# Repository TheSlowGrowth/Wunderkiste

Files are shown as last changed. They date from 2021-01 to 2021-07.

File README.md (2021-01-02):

# Wunderkiste




A portable music player for children

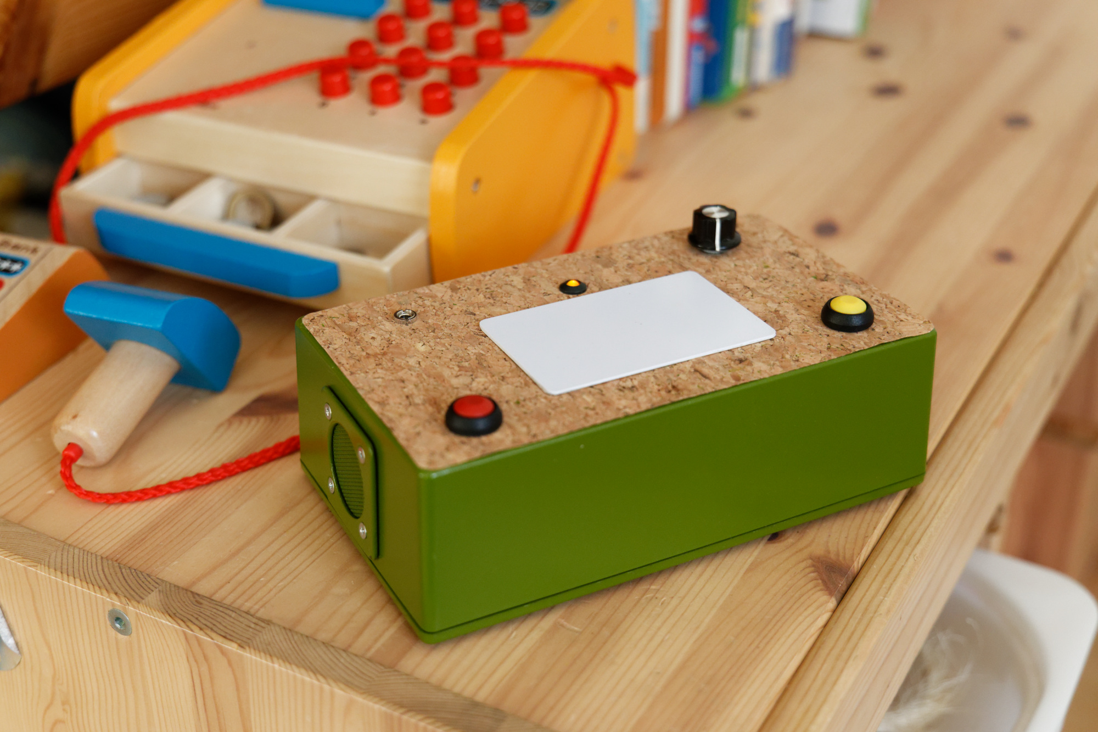
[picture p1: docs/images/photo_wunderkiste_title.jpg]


Wunderkiste is a portable music player for young children. It's designed to be very easy to use so that even a 2 year-old child can quickly understand how it works. The whole projects is entirely open source so that YOU can build and modify it easily.

- Music is selected by placing a card / tag / figurine / cuddly toy on the top surface of Wunderkiste.
- Speakers are integreated, but headphones can be used, too.
- The integrated battery lasts multiple days of heavy use and can simply be charged with a USB phone charger.
- Music is stored as `*.mp3` files on an SD card. Wunderkiste can hold a very large library of music.
- New music can easily be added without any special tools or software.
- The build uses mostly through-hole components and should be doable by anyone with basic knowledge of soldering and a handfull of tools.
- The firmware can be updated easily.

# Building and using Wunderkiste

We collected a lot of information in the [Wiki tab of this repository](https://github.com/TheSlowGrowth/Wunderkiste/wiki). Here are some links to get started:

- [Download the latest release](https://github.com/TheSlowGrowth/Wunderkiste/releases/latest)
- [View the user manual](https://github.com/TheSlowGrowth/Wunderkiste/wiki/3.-How-to-use) (Work in progress)
- [View the build guide](https://github.com/TheSlowGrowth/Wunderkiste/wiki/2.-How-to-build) (Work in progress)
- [Report issues and bugs](https://github.com/TheSlowGrowth/Wunderkiste/issues)
- [Any contribution to the project is highly appreciated!](https://github.com/TheSlowGrowth/Wunderkiste/wiki/5.-How-to-contribute-to-the-project)

# Project structure

This software repository is the place where we collect everything needed to build, use, improve and customize your Wunderkiste.

The repository contains
- The source code for the firmware in the `firmware` directory.
- The hardware design files for the printed circuit boards in the `hardware` directory.
- Documentation and guides in the `docs` directory.
- The sources for the [Wiki](https://github.com/TheSlowGrowth/Wunderkiste/wiki) in the `docs/wiki` directory. They are automatically copied to the project wiki when pull requests are merged.
- CI actions in the `.github` directory (automated tests, release artifacts generation, etc.)

In addition to that, the github page contains
- [The Wiki tab](https://github.com/TheSlowGrowth/Wunderkiste/wiki) where you'll find a lot of resources
- [The Releases tab](https://github.com/TheSlowGrowth/Wunderkiste/releases) where you'll find all releases and the corresponding firmware images and other documents.

# How to contribute

Wunderkiste is open to use and modify by everyone. When we work together on this project, we can truely make something unique and wonderful. Please don't be shy to help improve this project!

- If you find something that you feel needs an improvement, feel free to [open an issue on the issues tab](https://github.com/TheSlowGrowth/Wunderkiste/issues) and let us know.
- [Browse the issues tab](https://github.com/TheSlowGrowth/Wunderkiste/issues) to see what's to do and where help is needed.
- [Fork this repo and make some changes](https://guides.github.com/activities/forking/), then open a pull request. We'll review your changes and merge them into this repository.

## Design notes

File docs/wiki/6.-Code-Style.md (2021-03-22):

# Code Style

## General

- Use clang-format. The clang-format spec is enforced in pull requests.
- C++ files end on `.cpp`
- C files end on `.c`
- Header files for both languages end on `.h`
- C++ code is preferred over C code
- Each C++ header file has `#pragma once` 
- Each C header has an include guard: 
```cpp
#ifndef __DAC_H__
#define __DAC_H__

#endif // #ifndef __DAC_H__
```
- Use `""` for including local files, use `<>` for system headers
- Never use `using namespace` in a header file
- Where possible, unit tests are provided
- Avoid preprocessor macros where possible, use `static constexpr` variables instead
- Prefer `using TypeA = typeB` over `typedef TypeB TypeA;`
- Be generous with comments, use doxygen comments where it makes sense.
- No dynamic memory allocation. Allocate everything statically.

## Naming

- Use descriptive names
```cpp
int numBytesReceived; // good
int nRx; // bad
```
- Use camelCase 
```cpp
int numBytesReceived; // good
int num_bytes_received; // bad
```
- Types start with an upper case letter 
```cpp
class WavFileReader;
```
- Variables and function arguments start with an lower case letter 
```cpp
int numFilesWritten;
```
- Functions start with an lower case letter 
```cpp
void setupAudioOutput();
```
- Member variables end on an underscore to destinguish them from function arguments:
```cpp
class Counter 
{
private:
    int value_;
};
```
- Preprocessor macros are all upper case with snake_case_formatting:
```cpp
#define PLEASE_DONT_USE_MACROS_WHEN_POSSIBLE
```

## Strong types, safety, readability

- Prefer strong types
- Use `enum class` instead of `enum`
- Don't use raw pointers unless that's strictly required
- Prefer descriptive `enum class` arguments instead of `bool` arguments:
```cpp
setLeds(true, false, false); // bad
setLeds(Red::on, Blue::off, Green::off); // good
```
- Use `const` where possible:
```cpp
void doSomething(const int input); // good, communicates intention: This won't be changed during the function
void doSomething(int input); // bad, even though technically identical.
```
- Do not pass and return simple types by const ref
```cpp
int doSomething(); // good, copy the simple type
int& doSomething(); // bad, pass simple type by ref with no performance benefit, but security risks.
```
- Use `StaticVector<>` instead of C-style arrays
- Properly utilize `override` and `final`

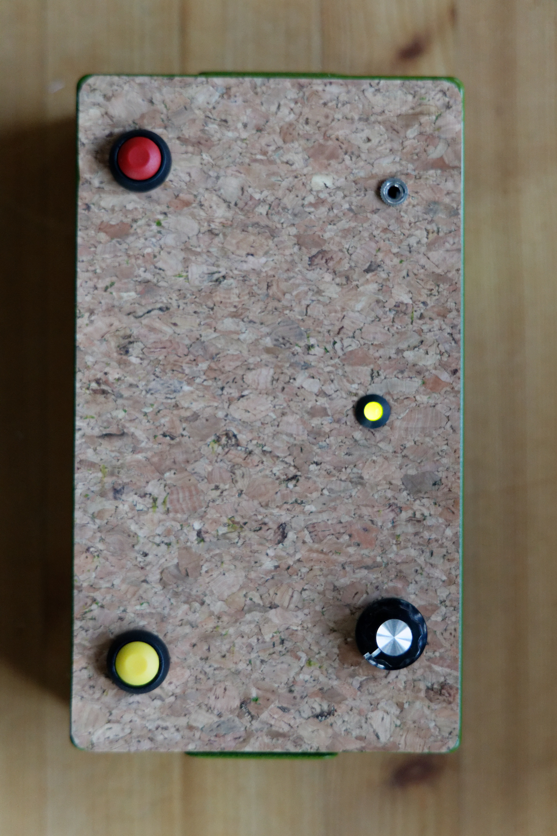
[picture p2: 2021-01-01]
docs/images/photo_top.jpg

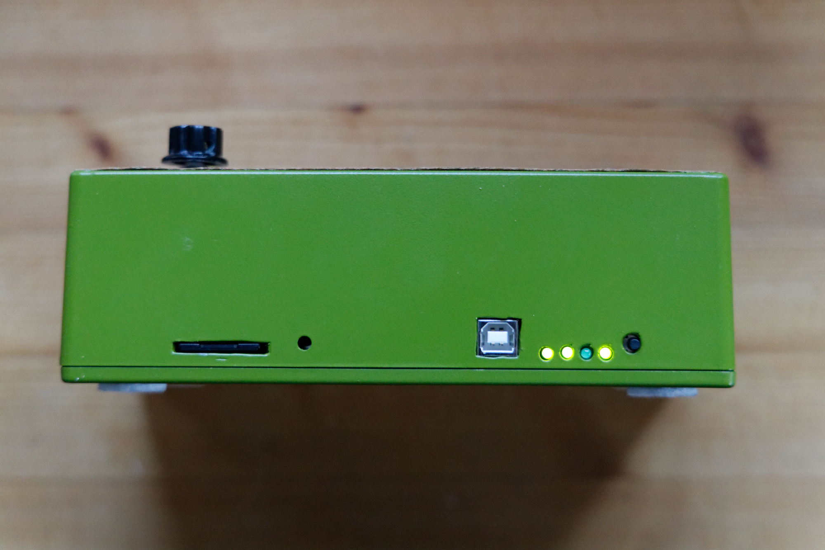
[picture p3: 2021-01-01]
docs/images/photo_back.jpg

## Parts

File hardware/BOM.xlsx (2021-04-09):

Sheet: Tabelle1
PCB designators | Description | Value | Count | reichelt.de part number | reichelt.de price per unit | reichelt.de total price | mouser.com part number | Notes
C1 C5 | Ceramic or Wima, >5V, 2.54mm pin pitch | 1u | 2 | Z5U-5 1,0µ | 0.27 € | 0.54 €
C7 C10 |  | 220n | 2 | Z5U-2,5 220N | 0.10 € | 0.21 €
C2 C3 |  | 100n | 2 | Z5U-2,5 100N | 0.06 € | 0.12 €
C4 |  | 47u | 1 | RAD FC 47/25 | 0.12 € | 0.12 €
C6 C8 C9 | Bipolar Electrolytic Capacitor | 10u Bipolar | 3 | SU-A 10U 50 | 0.21 € | 0.63 €
D1 D2 D3 D4 |  | LED | 4 | LED 3MM 2MA GN | 0.12 € | 0.48 €
D10 | Frontpanel LED R/G | 5mm, 3pin Common Anode, Red/Green | 1 | EVL 339-1SURSYGW | 0.20 € | 0.20 €
D5 D6 D7 D8 D9 |  | 1N5819 | 5 | 1N 5819 | 0.06 € | 0.30 €
J1 | Powerbank LED/Button cable | IDC Shrouded pinheader 2x5 | 1 | WSL 10G | 0.10 € | 0.10 €
 |  | IDC Socker 2x5 | 1 | PFL 10 | 0.10 € | 0.10 €
J10 | Headphones socket cable connector | Molex KK 6pin Pinheader | 1 | PSS 254/6G | 0.09 € | 0.09 € |  | Molex KK or similar, 2.54mm pin spacing
 |  | Molex KK 6pin Housing | 1 | PSK 254/6W | 0.07 € | 0.07 € |  | Molex KK or similar, 2.54mm pin spacing
J2 | SD Card Slot | SD-RSMT-2-MQ | 1 | 3M SDRSMT2MQ | 2.10 € | 2.10 €
J4 |  | 2x25 sockets | 2 | BL 2X25G8 2,54 | 0.62 € | 1.24 € | 200-SSW12501TD
J5 | USB charging connector | USB B socket Through Hole | 1 | RND 205-00858 | 0.25 € | 0.25 € |  | 2.54mm pin spacing; for the STM32F4 Discovery board
J6 J7 | PCB interconnect cable | IDC Shrouded pinheader 2x8 | 2 | WSL 16G | 0.14 € | 0.28 € |  | 2.54mm pin spacing
 |  | IDC Socket 2x8 | 2 | PFL 16 | 0.18 € | 0.36 € |  | 2.54mm pin spacing
J3 J9 | AudioIn & PowerBank Connectors | Molex KK 3pin Pinheader | 2 | PSS 254/3G | 0.05 € | 0.10 € |  | Molex KK or similar, 2.54mm pin spacing
 |  | Molex KK 3pin Housing | 2 | PSK 254/3W | 0.02 € | 0.04 € |  | Molex KK or similar, 2.54mm pin spacing
Q1 | P Channel Mosfet | BSP170P | 1 | BSP170P | 0.45 € | 0.45 €
R10 |  | 470R | 1 | METALL 470 | 0.08 € | 0.08 €
R11 |  | 2k2 | 1 | METALL 2,20K | 0.08 € | 0.08 €
R8 R9 R12 R14 R15 R17 |  | 10k | 6 | METALL 10,0K | 0.08 € | 0.49 € |  | get 10 for the same price due to the quantity discount
R13 R16 |  | 0R | 2 |  |  | 0.00 € |  | use wire bridges for full volume, attenuate volume with up to 50k resistors
R1 R2 R3 R4 R5 R6 R7 |  | 47k | 7 | METALL 47,0K | 0.08 € | 0.57 €
RV1 | Dual Gang 9mm Potentiometer | 50kA or 47kA, log, RK09 footprint, Alps/Alpha/… | 1 |  |  | 0.00 €
SW1 SW 2 | BatteryIndicator & Reset buttons | horizontal push button | 2 | TASTER 3305 | 0.21 € | 0.42 €
SW3 SW4 J8 J11 | Prev Bttn, Next Bttn, Speaker Connectors | Molex KK 2pin Pinheader | 4 | PSS 254/2G | 0.03 € | 0.12 €
 |  | Molex KK 2pin Housing | 4 | PSK 254/2W | 0.02 € | 0.08 €
U1 | Speaker Amplifier | TDA7266 | 1 | TDA 7266 | 1.70 € | 1.70 €
U2 | RFID Reader board | RFID_RC522_Board | 1 | DEBO RFID RC522 | 10.37 € | 10.37 € |  | better get this off ebay for MUCH cheaper
 |  | Crimp Pins Molex, pack of 20 | 2 | PSK-KONTAKTE | 0.29 € | 0.58 €
 | Volume Knob Cap | Mounts on RV1 | 1 | KNOPF 17-6 AL | 2.17 € | 2.17 €
 | STM32F407 Discovery board | STM32F407DISCOVERY | 1 | STM32 F407GDISC1 | 29.75 € | 29.75 € |  | Attention: Buy brand new so that you get one with version number MB997D for MUCH simpler drag&drop programming.
 | Frontpanel Pushbuttons |  | 2 | IS R3S RT | 5.80 € | 11.60 € |  | doesn't have to be that expensive, any momentary pushbutton will work just fine
 | LED frontpanel socket | 5mm | 1 | EBF A-5 S | 0.99 € | 0.99 €
 | Enclosure (screws included) | Hammond 1591XXEBK | 1 | 1591XXEBK | 9.35 € | 9.35 €
 | Headphone Jack | Stereo, switched, 3.5mm | 1 | LUM 1503-09 | 1.15 € | 1.15 € | 490-SJ1-3535 | the thread is a little short on this part but it's just enough
 | Speakers | Visaton BF 37 | 2 | VIS 2260 | 11.40 € | 22.80 €
 | Powerbank | Intenso A5200 | 1 | INTENSO 7322425 | 10.36 € | 10.36 €
 | SD Card |  | 1 | INTENSO SDHC16G | 3.49 € | 3.49 €
 | Screws for mounting the speakers & RFID | M2.5 countersunk, 10mm length max | 1 | SSK M2,5X10-200 | 2.70 € | 2.70 € |  | pack of 200
 | Nuts for mounting the speakers & RFID | M2.5 | 1 | SK M2,5-100 | 1.85 € | 1.85 € |  | pack of 100
 | Self tapping screws | # 4 x 1/4 |  |  |  | 0.00 € |  | for mounting PCB inside the Hammond enclosure; M2.5 screws might work as well
 | RFID cards, tags, stickers | Mifare Classik 1K compatible |  |  |  | 0.00 €
 | Speaker grille (?) | any metal mesh material | 1 | VIS SG 8210 | 8.95 € | 8.95 € |  | Any metal mesh will do. Cheap alternative: Frying Pan Grease Splash Guard
 | Cable, blue, 10m |  | 1 | LITZE BL | 0.78 € | 0.78 €
 | Cable, black, 10m |  | 1 | LITZE SW | 0.78 € | 0.78 €
 | Cable, red, 10m |  | 1 | LITZE RT | 0.76 € | 0.76 €
 | IDC flat cable |  | 1 | AWG 28-20F 3M | 5.25 € | 5.25 € |  | way too long. Maybe you have some leftover IDC cable from another project?
 | Rubber feet with adhesive |  | 1 | RND 455-00518 | 0.82 € | 0.82 € |  | pack of 55… some felt furniture feet will also work.
 | PCB material for the speaker covers |  | 1 | EP2CU 160X100 | 2.05 € | 2.05 €
 |  |  |  |  | Total price: | 110.45 €

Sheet: Tabelle2
Reference | Quantity | Value
C1 C5 | 2 | 1u
C7 C10 | 2 | 220n
C2 C3 | 2 | 100n
C4 | 1 | 47u
C6 | 1 | 10u
C8 C9 | 2 | 10u
D1 D2 D3 D4 | 4 | LED
D10 | 1 | LED_Dual_ACA
D5 D6 D7 D8 D9 | 5 | 1N5819
J1 | 1 | Conn_01x10
J10 | 1 | Headphones
J11 | 1 | Spkr_R
J2 | 1 | SD_Card_Det
J3 | 1 | Powerbank
J4 | 1 | STM32F4_Discovery
J5 | 1 | USB_B
J6 J7 | 2 | Conn_01x16
J8 | 1 | Spkr_L
J9 | 1 | AudioIn
Q1 | 1 | ISP75DP06LM
R10 | 1 | 470R
R11 | 1 | 2k2
R12 R14 R15 R17 | 4 | 10k
R13 R16 | 2 | 0R
R1 R2 R3 R4 R5 R6 R7 | 7 | 47k
R8 R9 | 2 | 10k
RV1 | 1 | 50kA
SW1 | 1 | BatteryIndicator
SW2 | 1 | Reset
SW3 | 1 | PrevTrack
SW4 | 1 | NextTrack
U1 | 1 | TDA7266
U2 | 1 | RFID_RC522_Board

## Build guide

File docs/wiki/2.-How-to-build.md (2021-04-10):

This guide collects all information you need to build Wunderkiste.

The build will take anywhere from a full day to multiple days depending on your tools and experience. This guide is written so that you can follow along step by step. Don't be afraid - some basic soldering experience should be the only thing you need to know to successfully finish this project.

Take your time, make breaks and keep your workspace clean. As often with tech-DIY projects it's well worth to build slowly and stay focussed. Being carefull now saves you a lot of hassle later in the troubleshooting process. Should something go wrong, there's always a way to recover. In this guide, there are troubleshooting tips with some common problems and solutions for them.

# What you should know before you start

Before you start, [download the latest release](https://github.com/TheSlowGrowth/Wunderkiste/releases/latest). It contains the firmware files, the bill of materials (BOM), drilling templates and more.

This project requires a lot of soldering. Most of it is pretty simple to do, but there are a couple of difficult parts, too. If you've done soldering projects in the past you don't have to worry. If you've never soldered anything before, I suggest you pick up a basic soldering project to get familiar with the process. It's certainly not rocket science and anyone can do it after a little bit of practice. Trying a cheap and small project first is ideal: You can quickly get familiar and feel the joy of success - but at the same time there's only a low risk and no expensive parts involved. Once you feel confident in your soldering you can safely start building a bigger project like Wunderkiste.

# Tools & Software

Before you get started, pick two boxes: One box for the parts, one box for the tools. Whenever you need to pause the build, you can just put everything back into the boxes and go on later.

These are the recommended tools for the electronics assembly:

- **An electronics soldering iron**. A cheap one will serve you well, but please get one that is temperature controlled. A soldering tip that is too hot or too cold will make it close to impossible to create good and reliable solder joints. Before you start with this project, you should have some basic soldering experience. 
- **"B series" soldering tip** for your soldering iron. I suggest a tip diameter of roghly 1-2mm. It seems counter-intuitive but smaller tips actually make it harder to create good solder joints because they don't have enough thermal mass and quickly drop in temperature as soon as you start soldering.
- **Resin core solder**.
- **Desoldering wick**. Don't even start without this. You'll need it at some point to suck away solder where you've applied too much.
- **Soldering flux**. Many people attempt to solder without proper flux. _That is a huge mistake_. Soldering flux is like magic: A) It makes the solder flow nicely instead of getting dry and sticky. B) It makes solder bridges separate. C) It makes you happy! The resin core inside the solder itself is enough for basic solder joints. But eventually, you'll end up with a solder joint that just won't "flow" and nothing seems to work. This is where flux comes to your rescue. **Don't get the stuff they sell at hardware stores.** It's meant for plumbing work and often it's corrosive. Get a "no clean" flux pen for fine pitch soldering work. Yes, it's expensive but it pays off.
- **Side cutters** for cutting wires, component legs and stripping isolation.
- **Tweezers and pliers**. Something basic is fine.
- **A hot glue gun**.
- **A deskmat**. I personally use a simple cardbord sheet. You'll regret not having used one once you burned a hole in your table :-)
- **A couple of zip ties** for attaching the battery pack
- **A vice** as a cheap crimp-tool for the IDC cables.
- **A simple multimeter** to measure voltages and continuity.

These tools are required for making the case:
- **A drill and drill bits in various sizes**.
- **A stepped drill bit** with 2, 4, 6, 8, 10 and 12mm steps is highly recommended for making the large holes for the front panel controls. 
- **A hole saw** for cutting the speaker holes. **TODO: Add diameter**
- **Screw drivers**. Flathead and Phillips
- **A "snap-off blade" utility knife** for cutting the SD card slot and the USB port opening.
- **Spray paint**. I suggest to use a plastic primer before and a clear coat after the actual paint job.

# Parts

Open the `BOM.xlsx` spreadsheet file you downloaded earlier. It contains all the electronic parts needed for the build, including order numbers for some webshops. If you can't get the exact same part, pick a replacement that matches the specifications written in the commentary columns.

The two circuit boards must be ordered from a PCB prototyping service like oshpark or any chinese PCB service. You can use the gerber productions files from the `gerbers` folder in `PCB_Files.zip`, which you downloaded earlier. Hopefully, if this project gains traction, we'll later be able to provide PCBs via webshops or group buys.

# Circuit board assembly

Open the interactive BOM from the `ibom` folder in `PCB_Files.zip`. It is a website generated from the circuit board design files where you can interactively find and view each component. In addition, you can checkmark what you've already completed.

Put aside the front panel LED. It's best to solder it with the PCB inserted into the case, so that it lines up nicely with the hole. It doesn't matter in which order you solder the remaining parts, but it is suggested to start with smaller ones and work towards the bigger parts like this:

1. Resistors (all parts named `R*`)
2. Capacitors (all parts named `C*`)
3. Diodes (all parts named `D*` - don't place the LEDs yet)
4. The power MOSFET Q1 and the speaker amplifier chip
5. The SD card slot - this is the trickiest of them so take your time and use flux
6. The volume potentiometer: Attention, it goes on the opposite side so that it faces upwards while all other components face downwards
7. All connectors and remaining parts.

The RFID board needs some special attention. 
1. Screw the RFID board in place using the M2.5 screws.
2. Observe the pins on the RFID board and the Wunderkiste PCB. These boards come with different pinouts.
3. Solder wire bridges between the board and the Wunderkiste PCB so that `MISO` connects to `MISO`, `SCK` connects to `SCK` and so on.

# Power bank installation

The power bank needs some special attention. At a minimum, you must attach a charging input wire, ground wire and an output wire to the power bank so that it can be connected to the 3pin Molex connector `J3` on the Wunderkiste bottom PCB. If you want, you can also break out the status LEDs and status button to the back of the Wunderkiste case by attaching wires for the ribbon cable `J1`. This is optional, though.

The instructions given here assume that you use the recommended Intenso A5200 power bank. Other power banks can work fine as well if they have the same features (USB 5V charging input port, USB 5V output port, physical button (no capacitive touch button) and up to 4 status LEDs).

1. Remove the stickers on both sides of the A5200 power bank. Under them you'll find screws which you have to remove. Aftwards, the plastic side pieces can be removed.
2. With the side pieces removed, push the internals out of the metal casing.
3. Undo the screws that attach the power bank PCB to the plastic frame so that you can reach the underside of the PCB.
4. Temporarily desolder the two battery wires (mark which wire goes to which terminal first!) so that the PCB is dead and safe to solder on.
6. Solder a black wire to the ground pin of the USB-A output connector.
7. Solder a red wire to the 5V pin of the USB-A output connector.
8. Find the 5V pin of the USB-micro-B input connector. The pins of the connector are super tiny, so you won't beable to attach a wire directly to them. However, you can follow the copper on the PCB to find a nearby spot which you can solder the wire to. There are different revisions of this power bank sold under the same name, but most of them have a test point close to the USB-micro-B input connector which you can directly solder the wire to.
9. Put the power bank onto its final spot on the PCB and shorten the three cables so that they reach the J3 connector nicely. Give them about 2cm extry length, just in case. It's a good idea to twist or braid the three cables so that they stay close together. Do that BEFORE you cut them to size.
10. Attach Molex metal contacts to each of the three wires and push them into the 3pin Molex KK connector housing so that they can be attached to `J3`. Be extra careful so that each wire ends up in the correct position! The silk screen markings next to `J3` indicate which wire goes where.
11. If you want to break out the status LEDs and the status button, follow these steps as well:
    1. Desolder the original button and LEDs from the power bank PCB. It usually helps to soak them in a generous blob of hot solder so that both pins can be undone at the same time. Be carefull not to damage any other components nearby. 
    2. Crimp a connector to one side of a 10pin ribbon cable. A vice will work just fine as a simple crimping tool.
    3. Cut the ribbon cable to size and separate at least 4cm of the wires on the other side so that they can be attached to various places on the power bank PCB.
    4. Take a look at the schematic PDF file from the `pdf` folder in `PCB_Files.zip`, which you downloaded earlier. Here you can see where the individual wires of `J1` need to be connected so that the button and LEDs on the Wunderkiste PCB end up connected to the corresponding pads on the power bank PCB.
    5. Start with the two wires for the status button. Remove the isolation and twist the individual copper wires. Soak them in solder. Afterwards, cut the wire end so that the exposed end is no longer than 2mm. Attach the wire to the contact pad on the power bank PCB.
    6. Do the same with the wires for each of the LEDs. Pay attention to the polarity. On the power bank PCB, you'll find little `+` markings next to each LED.
12. Reattach the battery wires to the pads from which you had disconnected them earlier.
13. Connect `J3` and `J1` to the Wunderkiste main PCB. Check that the status button and status LEDs work as intended. Connect a power source to the Wunderkiste USB socket and check that the power bank charges. Check that pin 1 of `J3` (marked `Discharge`) has 5V on it.
14. Disconnect `J1` and `J3`. Now that you know everything works, __carefully__ bend the wires so that the power bank PCB can be reattached to the plastic frame. After you're sure it fits, **soak** the power bank PCB in hot glue so that the fragile wires don't come off the first time you child drops the Wunderkiste to the floor.
15. Re-attach `J1` and `J3` and check once again that everything still works.
16. Finally, attach the power bank securely to the Wunderkiste PCB using zip ties.

Congratulations, this was the most fragile part of the Wunderkiste build and you rocked it!

# Speakers, buttons, jacks and other wiring

Connect red and black wires to the speaker `+` and `-` terminals respectively. Attach Molex KK contacts to the other ends and push them into the two 2pin Molex KK connector housings. It's not important which of the two pins is the `+` and the `-` side, but it's **very important** that you do it identically for both speakers. Otherwise one speaker would be moving inwards when the other moves outwards - effectively canceling each other out and resulting in a weak low frequency response.

Connect wires and Molex KK connectors to the two buttons in the same way. 

Connect wires and a 5 pin Molex KK connector to the 3.5mm headphone jack. The markings on the Wunderkiste PCB tell you which wire needs to go where: `Ring` needs to connect to the ring of the 3.5mm jack, `RingSw` connects to the switching contact that becomes disconnected from the `Ring` contact when a jack is pushed into the socket. The same goes for the `Tip` and `TipSw` contacts. Don't forget the `GND` contact that needs to be connected to the sleeve of the 3.5mm jack.

Solder three wires to the ground, tip and ring contacts of the headphone jack on the STM32F4 Discovery board. Braid or twist the wires and add a 3pin Molex KK connector to the other end so that it reaches the audio input connector `J9` on the top PCB.

Finally, crimp a connector to both sides of the 16 pin ribbon cable that will later connect the top and the bottom board.

# Power test

First, connect all parts together: Connect the speakers, buttons, audio input and the headphone jack to the top PCB. Connect the top PCB and bottom PCB with the ribbon cable. Insert the STM32F4 Discovery board into the sockets on the bottom PCB.

Press one of the buttons: You should see LEDs light up on the STM32F4 board AND on the RFID board which usually has its own little power LED. Release the buttons and the LEDs turn off. If that's not the case:
1. Check if there's ~5V on the `Discharge` pin of `J3`. If not, your power bank may be empty or the power bank wiring is not correct. You can connect a USB charger to the USB socket of Wunderkiste to continue with the tests.
2. Check that there's ~5V on the copper trace that connects `Q1`, `D5`, `D6` and `R7`. This is the input power __before__ the power switch MOSFET `Q1`.
3. Check that there's ~5V on the gate (pin 1) of MOSFET `Q1`. When you press one of the buttons, this voltage should drop to ~0V until you release the button again.
4. If conditions 1-3 are met then you should see ~5V on pin 2 and pin 4 of the MOSFET `Q1` while one of the buttons is pressed.

# Firmware installation

1. Connect a USB-mini-B cable to the STM32F4 Discovery board as shown in the image: 

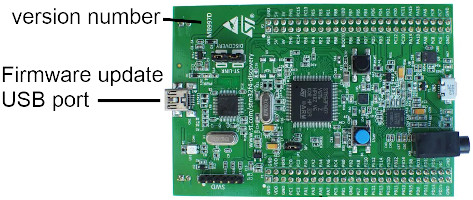
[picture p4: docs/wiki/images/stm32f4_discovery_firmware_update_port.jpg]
firmware update port


2. Connect the other end of the cable to a computer / phone / tablet where you'll see a "USB thumb drive" appear (In case it doesn't appear, check the version number as shown in the image above: It should read "MB997**D**". If the last letter is an A, B or C, your board is too old to support drag & drop flashing and you'll have to use another method of flashing the firmware, see the info box below.)
3. Copy the firmware `*.hex` file to the drive. This file was part of the Zip file you downloaded in the beginning. You should see an LED on the STM32F4 Discovery board flash red/green during the file transfer. 
4. After the transfer is complete, eject the drive (!) then disconnect the USB cable. The firmware update is now complete.

<details>
  <summary>How to update from older board versions!</summary>
  
  - If your board version is "MB997**A**" or "MB997**B**" or "MB997**C**", you can't simply program a new firmware by dragging and dropping a file. These boards have an older version of the programmer that doesn't support this feature.
  - The firmware download will be done with `openocd`, a commandline utility for debugging and flashing.
  - On windows:
    1. Download `openocd` from the [xpack project github release](https://github.com/xpack-dev-tools/openocd-xpack/releases). It probably doesn't contain an installer. Simply extract the folder contents somewhere on your harddrive, then add the path to `openocd.exe` (in the `bin` subdirectory) to your system PATH environment variable.
    2. Download and install the ST-LINK/V2-1 USB driver [from the ST website](https://www.st.com/en/development-tools/stsw-link009.html)
    3. Download the `*.hex` firmware image file [from the latest release](https://github.com/TheSlowGrowth/Wunderkiste/releases/latest)
    4. Open a command prompt `Start > Run > "cmd"`
    5. In the terminal window, navigate to the folder where you downloaded the `*.hex` firmware image using the `chdir` command: `chdir path\to\your\download\folder`
    6. Copy this line into the terminal window: `openocd.exe -f interface/stlink-v2-1.cfg -f target/stm32f4x.cfg -c init -c "reset init" -c "flash write_image erase Wunderkiste.hex" -c "verify_image Wunderkiste.hex" -c "reset run" -c shutdown`
    7. You should see a bunch of messages that ultimately say `verified XXX bytes in 0.XXXs (XX.XX KiB/s)` and `shutdown command invoked`
    8. The firmware download is complete.
  - On linux / macOS: 
    1. Download `openocd` from your package manager. (If that's not available, you may also use the [xpack project github release](https://github.com/xpack-dev-tools/openocd-xpack/releases). It probably doesn't contain an installer. Simply extract the folder contents somewhere on your harddrive.
    2. Open a terminal window. Add the path to the `openocd` executable file (in the `bin` subdirectory) to your search path with this command `export PATH="/path/to/openocd/binary:$PATH"`.
    3. Download the `*.hex` firmware image file [from the latest release](https://github.com/TheSlowGrowth/Wunderkiste/releases/latest)
    4. In the terminal window, navigate to the folder where you downloaded the `*.hex` firmware image using the `cd` command: `cd path/to/your/download/folder`
    5. Copy this line into the terminal window: `openocd -f interface/stlink-v2-1.cfg -f target/stm32f4x.cfg -c init -c "reset init" -c "flash write_image erase Wunderkiste.hex" -c "verify_image Wunderkiste.hex" -c "reset run" -c shutdown`
    6. You should see a bunch of messages that ultimately say `verified XXX bytes in 0.XXXs (XX.XX KiB/s)` and `shutdown command invoked`
    7. The firmware download is complete.
</details>

Remove the USB cable from the board.

# More testing

Now that the firmware is installed, we can finally do some actual tests.

1. Insert an empty, FAT32 formatted SD card into the SD card slot and temporarily put the front panel LED into the corresponding holes in the top PCB. We will solder this LED once the PCBs are installed in the case. For now it's enough to just stick it into the PCB loosly so that we can observe if the firmware is working as expected.
2. Press and hold one of the buttons. Power should turn on and **stay on** after you released the button. The front panel LED should light up in a steady green. 
    1. If the LED lights up in a steady red instead, you've inserted the LED in reverse. 
    2. If the LED blinks in red, Wunderkiste can't read the SD card. Make sure it is inserted and formatted as FAT32.
    3. If that doesn't help, check the SD card slot contacts and the resistors near the SD card slot.
3. After a while, the power will automatically turn off. Remove the SD card from the slot and put it in a computer. You should see a text file `library.txt`, which is empty.
4. Add a folder of mp3 files to the SD card, [as described in the user manual](https://github.com/TheSlowGrowth/Wunderkiste/wiki/3.-How-to-use#add-music-and-pair-it-to-a-card).
5. Insert the SD card back into the Wunderkiste card slot and hold one of the buttons so that Wunderkiste turns on. You should see the LED blinking in a green-orange pattern (this indicates that Wunderkiste wants to assign an RFID tag to the newly added folder of mp3 files). Also the music from the new folder should start playing. If not:
    1. Try turning the volume knob. Maybe it was turned down?
    2. Try inserting headphones into the headphone jack. Can you hear something in the headphones? If yes, your speaker amplifier sections needs some fixing.
    3. If you can't get audio from the headphone jack, plug headphones directly into the audio output of the STM32F4 Discovery board (Attention: Loud!). You should hear audio playing. 
6. Put an RFID tag on top of the RFID reader board. Keep ~1-2cm distance to the board for optimal detection. The status LED should start flashing rapidly in green to indicate that the RFID tag was assigned to the new folder.
7. Remove the RFID tag. The status LED returns to a steady green and the music stops.
8. Put the RFID tag back. The music should start playing and the status LED will be orange. Check that you can navigate forwards and backwards through the mp3 files with the two buttons.

Congratulations, your Wunderkiste seems to work perfectly!

# Case assembly

Here you can get very creative! Any kind of case works, as long as it doesn't block the RFID signals.
The instructions here assume you're using the recommended Hammond plastic case.

1. Print out the drill template from the `pdf` folder in `PCB_Files.zip`, which you downloaded earlier. Make sure that the dimensions are accurate - use the test ruler on the print to see if you accidentally scaled it.
2. Place the template on the __inside__ of the top piece of the case (not the lid! The lid is the bottom side of the finished case).
3. Align the mounting posts on the inside of the case with the markings on the drill template. Use a center punch or a nail to mark the center of the drill holes for the volume potentiometer, status LED, headphone jack and the two buttons.
4. Drill the holes with a stepped drill bit and verify that all the components fit through the holes nicely.
5. Stick the status LED in the holes in the top PCB (check the polarity, otherwise red and green will be reversed!), then mount them into the case with the self tapping screws. You'll need some standoffs so that the PCB is ~10mm below the surface of the case. 
6. Solder the status LED. Now it's nicely aligned with your drill hole. You can now remove the top PCB from the case again.
7. Mount the bottom pcb on the "lid" of the case. Place the lid on the top part of the case and mark where you'll have to drill the holes for the status button, status LEDs and the reset button. Drill the holes. Remember that the reset button won't stick out of the hole - it's activated by sticking a needle / nail / wire into the hole, just like on other devices. Consequently, this hole can be much smaller than the other holes.
8. Again, place the lid of the case onto the top of the case and check that the LEDs and the status button match with the holes.
9. Mark where you'll have to make the cutout for the USB port and the SD card slot. For these, it's recommended to drill small holes around the perimeter of the cutouts and finish them with a "snap-off blade" utility knife. Fortunately the plastic of the case is very soft and you can easily cut it with the knife. It's tedious but easy.
10. Measure the distance between the mounting holes on the speaker drivers. Make a small drill template from paper where the center of the speaker and the four mounting holes are marked. Use a nail or center puncher to transfer the markings to the side of the case.
11. Use a circular drill bit to make the cutouts for the speakers on both side of the case - using the center marking your created with the template. The speakers mount from the inside of the case. The hole should allow the membrane to move freely while the metal frame of the speaker driver is mostly hidden inside the case.
12. Drill the four mounting holes for both of the speakers. 
13. To make the speaker covers, cut two square pieces of raw PCB material. They should be large enough to cover the speaker cutouts and the speaker mounting holes entirely. Drill the mounting holes and the speaker cutout into the two speaker covers. Sand the edges.
15. Cut two pieces of metal mesh material (e.g. from a frying pan grease splash guard) so that they can be sandwiched between the case and the covers that you made in the previous step. Also make holes for the four mounting screws.
16. Test the speaker covers by mounting them like this: 
    1. Place the mesh material onto the side of the case. 
    2. Add the speaker covers on top.
    3. Put M2.5 bolts through the covers, mesh and case.
    4. Add the speaker driver from the inside of the case.
    5. Secure the bolts with nuts from the inside of the case.
17. Now you can assemble the entire Wunderkiste and check if it all fits together. If the 16pin ribbon cable between the two PCBs is too long, it can push on the reset button on the STM32F4 Discovery board when the lid is closed. This would stop it from booting up. You can simply remove the reset button cap. That makes the button much smaller and harder to press accidentally. 
18. After you confirmed that it all works as intended, disassemble everything and paint the case.
19. After the paint is dry, add another coat of clear paint as a protection layer.
20. Consider glueing a layer of thin cork to the surface so that RFID tags don't slide off the top surface easily.

You're done! Congratulations!

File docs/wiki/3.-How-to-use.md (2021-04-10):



Wunderkiste is a music player for children. Its controls are extremly simple so that it can be used by children as young as 3 years. 
This manual contains all information needed to use it.

# Controls

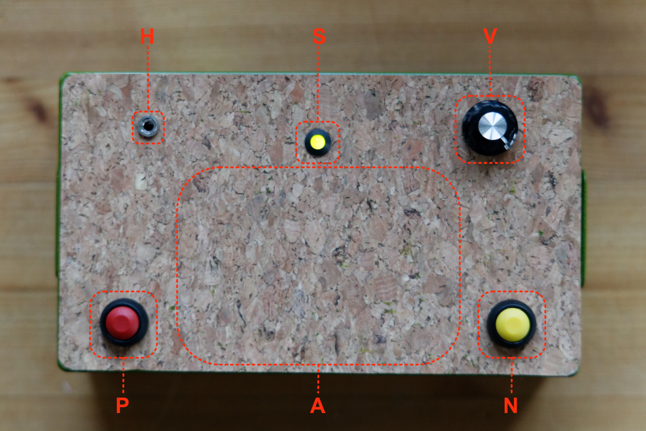
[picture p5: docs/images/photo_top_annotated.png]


 <table>
  <tr>
    <td><b>H</b></td>
    <td>Headphone jack. Mutes internal speakers when headphones are plugged in.</td>
  </tr>
  <tr>
    <td><b>S</b></td>
    <td>Status LED. Indicates what Wunderkiste is doing.</td>
  </tr>
  <tr>
    <td><b>V</b></td>
    <td>Volume control.</td>
  </tr>
  <tr>
    <td><b>P</b></td>
    <td>"Prev" button. Jumps to the previous track.</td>
  </tr>
  <tr>
    <td><b>A</b></td>
    <td>RFID - active "card area". Place cards / tags here.</td>
  </tr>
  <tr>
    <td><b>N</b></td>
    <td>"Next" button. Jumps to the next track.</td>
  </tr>
</table> 

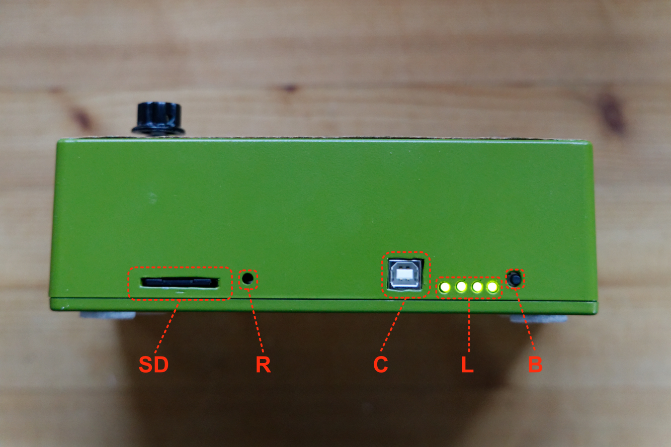
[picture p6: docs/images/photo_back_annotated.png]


 <table>
  <tr>
    <td><b>SD</b></td>
    <td>SD card slot.</td>
  </tr>
  <tr>
    <td><b>R</b></td>
    <td>"Reset" button. Push with a pointy object to reset <br/> the Wunderkiste in case it hangs due to a software error.</td>
  </tr>
  <tr>
    <td><b>C</b></td>
    <td>Charging port. Connect to a USB phone charger to charge the internal battery.</td>
  </tr>
  <tr>
    <td><b>L</b></td>
    <td>Battery indicator LEDs. Show the battery level. (Optional)</td>
  </tr>
  <tr>
    <td><b>B</b></td>
    <td>"Battery" button. Activates the battery indicator LEDs. (Optional) </td>
  </tr>
</table> 

# Basic operation

1. Each piece of music is represented by a plastic RFID card. Alternatively, tags, figurines, etc. can be used instead.
2. Wake up your Wunderkiste by pressing (and holding) one of the buttons **P** or **N** until the status LED **S** lights up in green.
3. Place a card on the card area **A**. Wunderkiste will start playing the corresponding music from its SD card and the status LED **S** will turn yellow.
4. While the music is playing, press the **N** and **P** buttons to jump to the next / previous track.
5. To stop playback, simply remove the card from the card area **A**. The status LED **S** returns to green.
6. After a while of inactivity, Wunderkiste goes back to sleep. The status LED **S** turns off.
7. If there is an error, the status LED will start flashing in a pattern of red/green/yellow to show you what's wrong.

# Manage the music library

Each card plays MP3 files from a single folder on the SD card in alphabetical order. To determine which folder to play when a specific card is placed on the card area **A**, Wunderkiste maintains a _library_ that links folder names to the RFID cards. This library is stored in the `library.txt` file that Wunderkiste will automatically create on the SD card. Usually you don't have to edit this file, Wunderkiste will take care of it. 

## Prepare an SD card

Wunderkiste needs the SD card to be formatted as FAT32. Thankfully, new cards usually come formatted as FAT32 and you can just use them as-is. 

If you get the red long red long red long error code when you wake up your Wunderkiste then you'll have to manually format the card before it can be used like this:

1. Format the card on a computer. On Windows, right click the card in Windows Explorer and select `Format`. On macOS, you can use the `Disk Utility` app to format the card. Make sure to select FAT32 as the file system. Usually this fixes any issues, but there are special cases where this doesn't work due to weird partitions on the card.
2. A safer way could be this: Insert the card into a digital camera and format the card via the camera menu. Most cameras use the FAT32 file system as well. The camera will most likely add some folders, like `DCIM` or `MISC`. Make sure to delete all of them so that the card is entirely empty before you use it with Wunderkiste. 

If Wunderkiste still can't read the card, try using another one.

## Prepare cards / tags for use with Wunderkiste

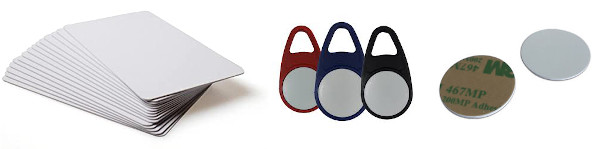
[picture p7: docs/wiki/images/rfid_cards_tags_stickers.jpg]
rfid cards, tags and stickers


Wunderkiste uses RFID to detect objects that are placed on the active area **A**. There are various types of plastic cards, tags or stickers that work with Wunderkiste. They are usually quite cheap at online retailers. Here's what you need to know, when selecting cards / tags:

1. Search for "Mifare Classic 1K". This is an RFID protocol that Wunderkiste can read. You'll find various types of cards, tags and stickers, just like the ones in the pictures above.
2. The RFID chip in Wunderkiste is called _MFRC 522_ or _RC 522_ and it is used in many DIY projects. Usually, cards / tags are specifically sold as "MFRC 522 compatible".
3. To make the cards / tags easily recognizable for children you can modify them with photos, attach them to figurines or embed them in cuddly toys. Just make sure that the RFID chip inside the card / tag remains close to the surface of Wunderkiste so that the RFID communication is not negatively affected. My preferred choice are white RFID cards to which I glue a photo of the story / music associated with that card. For this, I print a photo on a photo printer and simply glue it to the card. The resulting cards are easy to handle, robust and can simply be put in a small box. They tend to get lost though, so using bigger objects can be beneficial, too. 
4. Before you invest time and effort into customizing the RFID cards / tags, [I suggest you pair them with music](#add-music) so that you can easily check if they work.

## Add music and pair it to a card

1. Add new music by copying folders of `*.mp3` files to the SD card. Each folder will later be linked to its own unique card. Place each folder directly in the root directory of the SD card, **don't use subfolders**. You can add multiple folders at once.
2. Place the SD card into the card slot on your Wunderkiste. 
3. Wake up your Wunderkiste by pressing (and holding) one of the buttons **P** or **N** until the status LED **S** lights up. Wunderkiste now detects that there are new folders for which it doesn't know a corresponding card yet. 
4. The status LED **S** starts blinking green short green short yellow very long and music from one of the new folders starts playing. Wunderkiste now waits for you to tell it which card should be linked to this folder.
5. Place an **unused** card (= not linked to any other folder) on the card area **A**. Wunderkiste will link this card to the folder and the status LED **S** starts rapidly flashing in green green short green short green short to indicate that the folder was successfully linked to this card.
6. Remove the card from the card area **A**. If there are more unlinked folders, Wunderkiste starts playing the next folder (go back to 4.)
7. Once all folders are linked to their own unique cards, the status LED **S** lights up in green and Wunderkiste is ready to be used.

## Remove music

1. Locate the folder on the SD card that contains the music you want to remove and delete the entire folder.
2. Open the `library.txt` file on the SD card with a text editor.
3. You'll see many lines like this `<Some characters>:<A folder name>`. Locate the line for the folder which you just deleted and erase it. Then save the file. Now the card that was used for this folder is free to be used for new folder.

## Change/reset the card for a folder

If you would like to use a different card for a folder of music (= unlink the current card and link a new one), you'll have to remove the corresponding entry from the Wunderkiste library.

1. Open the `library.txt` file on the SD card with a text editor.
2. You'll see many lines like this `<Some characters>:<A folder name>`. Locate the line for the folder for which you'd like to change the card and erase it. Then save the file.
3. Place the SD card into the card slot on your Wunderkiste. 
4. Wake up your Wunderkiste by pressing (and holding) one of the buttons **P** or **N** until the status LED **S** lights up. Wunderkiste now detects that there is a folder for which it doesn't have a linked card yet. Follow the pairing process [described above](#add-music).

# Status LED codes

The status LED can be lit continuously or blink in a pattern to display what Wunderkiste is currently doing. 

| LED pattern | Description |
| ---- | ---- |
| off | Wunderkiste is sleeping. Wake it up by pressing (and holding) one of the buttons **P** or **N** until the status LED **S** lights up. If that doesn't work, the battery may be empty. Connect Wunderkiste to a charger and try again. |
| green short (continuous) | Wunderkiste is awake and ready to play music for you. Place a card on the card area **A**. |
| yellow short (continuous) | Wunderkiste is playing music. |
| red long red long red long ---- | Wunderkiste can not read the SD card. [Make sure that it is formatted to a FAT32 file system](#prepare-card). |
| green short green short yellow very long | _Pairing:_ Wunderkiste plays a folder of music that is not yet linked to a card. Place an **unused** card on the card area to link it to this folder |
| green short green short green short | _Pairing:_ Wunderkiste has successfully linked the card to the folder that is currently playing. Please remove the card to finish the pairing process. |
| red short red short red short | _Pairing:_ There was an error while trying to link the card to the folder that is currently playing. Please remove the card and try again with another card. Possible reason: The card was already in use for another folder. |
| red short red short - red short red short - red short red short ---- | An internal error occured. Ooops. That should not happen. Please help fix this issue by providing a bug report on the [issues page](https://github.com/TheSlowGrowth/Wunderkiste/issues)!|

# Update the firmware

The firmware can be updated easily like this:

1. Download the `*.hex` firmware image file [from the latest release](https://github.com/TheSlowGrowth/Wunderkiste/releases/latest)
2. Remove the SD card from the card slot.
3. Open the Wunderkiste case by removing the 6 screws from the bottom panel. Tilt the panel slightly along the back edge so that the USB connector and battery status LEDs can retract from their cutouts in the top piece of the case.
4. Now that the case is open, connect a USB cable to the firmware update port on the STM32F4 Discovery board, as shown in the image: 

firmware update port

5. Connect the other end of the cable to a computer / phone / tablet where you'll see a "USB thumb drive" appear (In case it doesn't appear, check the version number as shown in the image above: It should read "MB997**D**". If the last letter is an A, B or C, your board is too old to support drag & drop flashing and you'll have to use another method of flashing the firmware, see the info box below.)
6. Copy the firmware `*.hex` file to the drive. You should see an LED on the board flash red/green during the file transfer. 
7. After the transfer is complete, eject the drive (!) then disconnect the USB cable. The firmware update is now complete.

<details>
  <summary>How to update from older board versions!</summary>
  
  - If your board version is "MB997**A**" or "MB997**B**" or "MB997**C**", you can't simply program a new firmware by dragging and dropping a file. These boards have an older version of the programmer that doesn't support this feature.
  - The firmware download will be done with `openocd`, a commandline utility for debugging and flashing.
  - Open the case of your Wunderkiste as described above and connect the USB cable to the firmware update port.
  - On windows:
    1. Download `openocd` from the [xpack project github release](https://github.com/xpack-dev-tools/openocd-xpack/releases). It probably doesn't contain an installer. Simply extract the folder contents somewhere on your harddrive, then add the path to `openocd.exe` (in the `bin` subdirectory) to your system PATH environment variable.
    2. Download and install the ST-LINK/V2-1 USB driver [from the ST website](https://www.st.com/en/development-tools/stsw-link009.html)
    3. Download the `*.hex` firmware image file [from the latest release](https://github.com/TheSlowGrowth/Wunderkiste/releases/latest)
    4. Open a command prompt `Start > Run > "cmd"`
    5. In the terminal window, navigate to the folder where you downloaded the `*.hex` firmware image using the `chdir` command: `chdir path\to\your\download\folder`
    6. Copy this line into the terminal window: `openocd.exe -f interface/stlink-v2-1.cfg -f target/stm32f4x.cfg -c init -c "reset init" -c "flash write_image erase Wunderkiste.hex" -c "verify_image Wunderkiste.hex" -c "reset run" -c shutdown`
    7. You should see a bunch of messages that ultimately say `verified XXX bytes in 0.XXXs (XX.XX KiB/s)` and `shutdown command invoked`
    8. The firmware download is complete.
  - On linux / macOS: 
    1. Download `openocd` from your package manager. (If that's not available, you may also use the [xpack project github release](https://github.com/xpack-dev-tools/openocd-xpack/releases). It probably doesn't contain an installer. Simply extract the folder contents somewhere on your harddrive.
    2. Open a terminal window. Add the path to the `openocd` executable file (in the `bin` subdirectory) to your search path with this command `export PATH="/path/to/openocd/binary:$PATH"`.
    3. Download the `*.hex` firmware image file [from the latest release](https://github.com/TheSlowGrowth/Wunderkiste/releases/latest)
    4. In the terminal window, navigate to the folder where you downloaded the `*.hex` firmware image using the `cd` command: `cd path/to/your/download/folder`
    5. Copy this line into the terminal window: `openocd -f interface/stlink-v2-1.cfg -f target/stm32f4x.cfg -c init -c "reset init" -c "flash write_image erase Wunderkiste.hex" -c "verify_image Wunderkiste.hex" -c "reset run" -c shutdown`
    6. You should see a bunch of messages that ultimately say `verified XXX bytes in 0.XXXs (XX.XX KiB/s)` and `shutdown command invoked`
    7. The firmware download is complete.
</details>

# Troubleshooting tips 

### My music sounds weird (pitched up/down, too fast/slow)
Please make sure that the `*.mp3` files are at a sample rate of 44.1kHz (standard CD sample rate). If not, you can use an audio editor like Audacity to convert the files to 44.1kHz.

### Wunderkiste just hangs and doesn't react
You probably hit a bug in the firmware. Oops. Sorry! Use a pointy object (e.g. paper clip) to press the reset button **R** on the back of your Wunderkiste. This should switch it off so that you can wake it up again. Please help fix the issue by providing a bug report on the [issues page](https://github.com/TheSlowGrowth/Wunderkiste/issues)!

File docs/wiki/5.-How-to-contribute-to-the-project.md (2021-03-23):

# Why and what

Wunderkiste is free and open source. We maintain and develop this project because we think it's a great device for children and a cool project to build for your kids.
Any contribution is valuable and helps move the project forward! **Don't be shy, get your hands dirty!**

Help is needed in various places. Coding skills are not strictly required!
- Spread the word, tell others about this project!
- Help each other building your own Wunderkiste!
- Ask questions, report bugs or suggest improvements on the [issues tab of this repository](https://github.com/TheSlowGrowth/Wunderkiste/issues).
- Improve the documentation (see below)!
- Improve the hardware (see below)!
- Improve the firmware (see below)!

Direct contributions to the source code or documentation generally follow the github forking mechanism [which is nicely explained here](https://www.dataschool.io/how-to-contribute-on-github/). 
1. You fork the repository
2. You make and commit a change on a feature branch
3. You create a pull request with a description of your changes.
4. The automated tests run and results are visible in the pull request
5. Your pull request is discussed, changes are suggested and finally ...
6. ... the pull request is merged.

# Contributing to the documentation

The documentation is provided in the wiki tab of this repository. To make a change to the documentation, you edit the files in the `docs/wiki/` directory and create a pull request with these changes.
Once the changes are merged, they'll be automatically copied to the [wiki tab](https://github.com/TheSlowGrowth/Wunderkiste/wiki) of the Wunderkiste project.

# Contributing to the hardware

The Wunderkiste hardware is designed using [KiCad EDA](https://kicad.org/). Gerber files, schematics pdf, drill templates, BOM, etc. are automatically generated for each new release.
To make a change to the hardware design, please edit the files in the `hardware` directory and create a pull request with these changes.

# Contributing to the firmware

To setup your development environment for firmware development, check out [this wiki page](https://github.com/TheSlowGrowth/Wunderkiste/wiki/4.-How-to-setup-for-development).

- Please [follow the code style](https://github.com/TheSlowGrowth/Wunderkiste/wiki/6.-Code-Style)
- Provide unit tests where possible

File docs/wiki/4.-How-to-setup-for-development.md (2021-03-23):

# Overview

Development for the Wunderkiste firmware can be done with many different tools, but here's the recommended setup:

- `git` for sourcecode management
- `Visual Studio Code` as a text editor / debugging host / IDE
- `clang-format` auto-formatting
- `gcc-arm-none-eabi` compiler and toolchain (version 9-2020-q2-update)
- `openocd` gdb debugging server for connecting to the board

# Setup instructions

## Git and Github

Wunderkiste is hosted as a git repository. It is helpful to have a basic understanding of what git is and how it's used. I recommend to read [this tutorial](https://guides.github.com/introduction/git-handbook/) if you feel unsure.

`git` can be fully used from the command line, but many prefer to user a graphical user interface like [Fork](https://git-fork.com/), [Sourcetree](https://www.sourcetreeapp.com/) or [Github Desktop](https://desktop.github.com/). Any of these will be very helpful for a beginner as they visualize the history of changes and the state of your local working copy of the code.
A graphical git client (like the ones mentioned above) often brings its own version of git, so you usually don't have to install your own version of `git`.

If you plan on contributing code to the project, you'll need an account on github. Also make sure to configure your git client (or your local git installation) so that any changes (commits) you make to the code are correctly attributed to your user account on github. [Here's a guide that shows you how to do that while hiding your personal email adress](https://www.meziantou.net/hide-your-email-address-on-github.htm). A graphical git client (like the ones mentioned above) typically allows you to configure these settings via their own settings dialog.

## clang-format

`clang-format` is a handy tool for helping you to tidy up your code formatting. It can assist you in fixing indentation, spacing and line breaks to provide a clean, even code style across the project.
You don't have to use this tool, but i would recommend to have it installed.

- Windows: Download and install the LLVM setup from [here](https://llvm.org/builds/)
- linus: Just use your local package manager to install it
- macOS: Homebrew can be used to install clang-format

## gcc-arm-none-eabi

`gcc-arm-none-eabi` is the compiler and toolchain used to build the Wunderkiste source code. Wunderkiste currently uses the version `9-2020-q2-update`. Other versions will likely work but produce slightly different machine code. This will typically be irrelevant but we recommend top stick to this version nonetheless.

- Windows:
    1. Download the `9-2020-q2-update` installer from https://developer.arm.com/tools-and-software/open-source-software/developer-tools/gnu-toolchain/gnu-rm/downloads
    2. Install to the default directory for seamless integration with the build environment: `C:\Program Files (x86)\GNU Arm Embedded Toolchain\9 2020-q2-update`
- macOS / linux:
    1. I recommend simply to place the toolchain into a folder and not use any particular installer. This allows you to use different versions along each other.
    2. Download the `9-2020-q2-update` archive from https://developer.arm.com/tools-and-software/open-source-software/developer-tools/gnu-toolchain/gnu-rm/downloads
    3. Extract to this directory for seamless integration with the build environment: `~/dev/gcc-arm-none-eabi-9-2020-q2-update`

## Various other build tools

During the build process, various other build tools are required. 

- Windows:
    1. These linux-like build tools are provided via `cygwin`.
    2. Download the [cygwin installer from the cygwin website](https://www.cygwin.com/setup-x86_64.exe)
    3. Run the installer and install the following packages:
        - gcc-core
        - gcc-g++
        - gdb
        - make
        - pkg-config
- macOS:
    1. Install Xcode and the Xcode command line utilities
- linux:
    1. Install the `build-essential` package via your package manager.

## openocd & hardware drivers

`openocd` connects to the Wunderkiste hardware, programs it and is a debugging server for gdb.

- Windows:
    1. Download and install `openocd` from the [xpack project](https://github.com/xpack-dev-tools/openocd-xpack/releases)
    2. Make sure it is available via the system PATH variable
    3. Download and install the ST-LINK/V2-1 USB driver [from the ST website](https://www.st.com/en/development-tools/stsw-link009.html)
- macOS:
    1. Download and install `openocd` from the [xpack project](https://github.com/xpack-dev-tools/openocd-xpack/releases)
    2. Make sure it is available via the system PATH variable
- linux:
    1. Install `openocd` via your package manager.

## Visual Studio Code

Any text editor can be used to modify the source code. However, it is recommended to use [Visual Studio Code](https://code.visualstudio.com/) as the Wunderkiste project provides integration files for
- syntax highlighting
- compiling
- debugging
- auto-formatting

1. Download and install [Visual Studio Code](https://code.visualstudio.com/)
2. Install the following extensions:
    - C/C++ (syntax highlighting, auto-completion, etc.)
    - Clang-Format (auto-formatting via a keyboard shortcut)
    - GoogleTest Adapter (for displaying and running the unit tests locally)

# First steps

1. Open your git client and clone the Wunderkiste repository to a location of your choice. Make sure to also checkout the submodules.
2. Open that folder in Visual Studio Code.
3. Press `Ctrl-Shift-B` or `Cmd-Shift-B` and run the `build-Wunderkiste` task.
4. The code should compile - if not: Check the output from the Visual Studio Code terminal to see what's missing.
5. To run a debugging session: 
    1. Connect the board to your computer via a USB cable. Connect to the USB-mini-B connector on the ST-Link side of the board, not the USB-micro-B connector on the other side.
    2. Click on the `Run and Debug` tab on the left of the Visual Studio Code window.
    3. Run the `Launch On Hardware` job. A debugging session should start.
6. To run the unit tests locally:
    1. Click on the `Run and Debug` tab on the left of the Visual Studio Code window.
    2. Run the `Launch Tests Locally` job.
    3. You can also run tests from the `Test` tab on the left of the Visual Studio Code window.
7. You can build the firmware directly from the commandline by executing `make all` in the `firmware` directory
8. You can program the firmware directly from the commandline by executing `make upload` in the `firmware` directory
9. You can build the unit tests directly from the commandline by executing `make` in the `firmware/tests` directory
9. You can run the unit tests directly from the commandline by executing `Wunderkiste_gtest(.exe)` in the `tests/build/bin/` directory

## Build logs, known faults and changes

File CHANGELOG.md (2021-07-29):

# Change Log

All notable changes to this project will be documented in this file.

## [0.5] (2021-07-29)

- display correct error code when SD card can't be mounted
- improve reliability of SD card by unmounting before shutdown
- retry mounting SD card multiple times when card is not immediately ready

## [0.4] (2021-04-10)

- increase maximum path length to allow playback of files with very long file namea
- small improvements to BOM.xlsx
- add BOM.xlsx to the release artifacts
- apply clang-format rules to all application and test source code files
- remove obsolete and unused files that were leftover from the initial v0.1 firmware

## [0.3a] (2021-03-22)

- bugfixes
- fixe release CI action

## [0.2] (2021-03-20)

- firmware rewrite in C++
- improve reliability

## [0.1] (2020-12-30)

- initial release

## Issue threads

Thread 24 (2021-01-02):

"Internal error" during playback

TheSlowGrowth, 2021-01-02:
While playing music, sometimes an "internal error" is triggered so that the status LED shows the "internal error" pattern. It seems related to #1 as it typically occurs at the transition from one file to another. Probably caused by incorrect handling of mp3 decoder return codes.

Closed 2021-03-22.

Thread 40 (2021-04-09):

Automatically split bottom/top boards before gerber export

TheSlowGrowth, 2021-04-09:
Currently the gerber files include both the top and bottom boards in one single set of gerber files. This is not supported by most PCB fabs. Using python scripting we could try to remove components and traces from the Kicad pcb files prior to the export like this:

```
import pcbnew

def isAllowed(position):
    return position.y > 160

pcb = pcbnew.LoadBoard("Wunderkiste.kicad_pcb")

for module in pcb.GetModules():
    ref = module.GetReference()
    print("- Module: " + ref)
    p = module.GetPosition()
    if not isAllowed(p):
        pcb.Delete(module)

pcb.Save("Wunderkiste_topOnly.kicad_pcb")
```

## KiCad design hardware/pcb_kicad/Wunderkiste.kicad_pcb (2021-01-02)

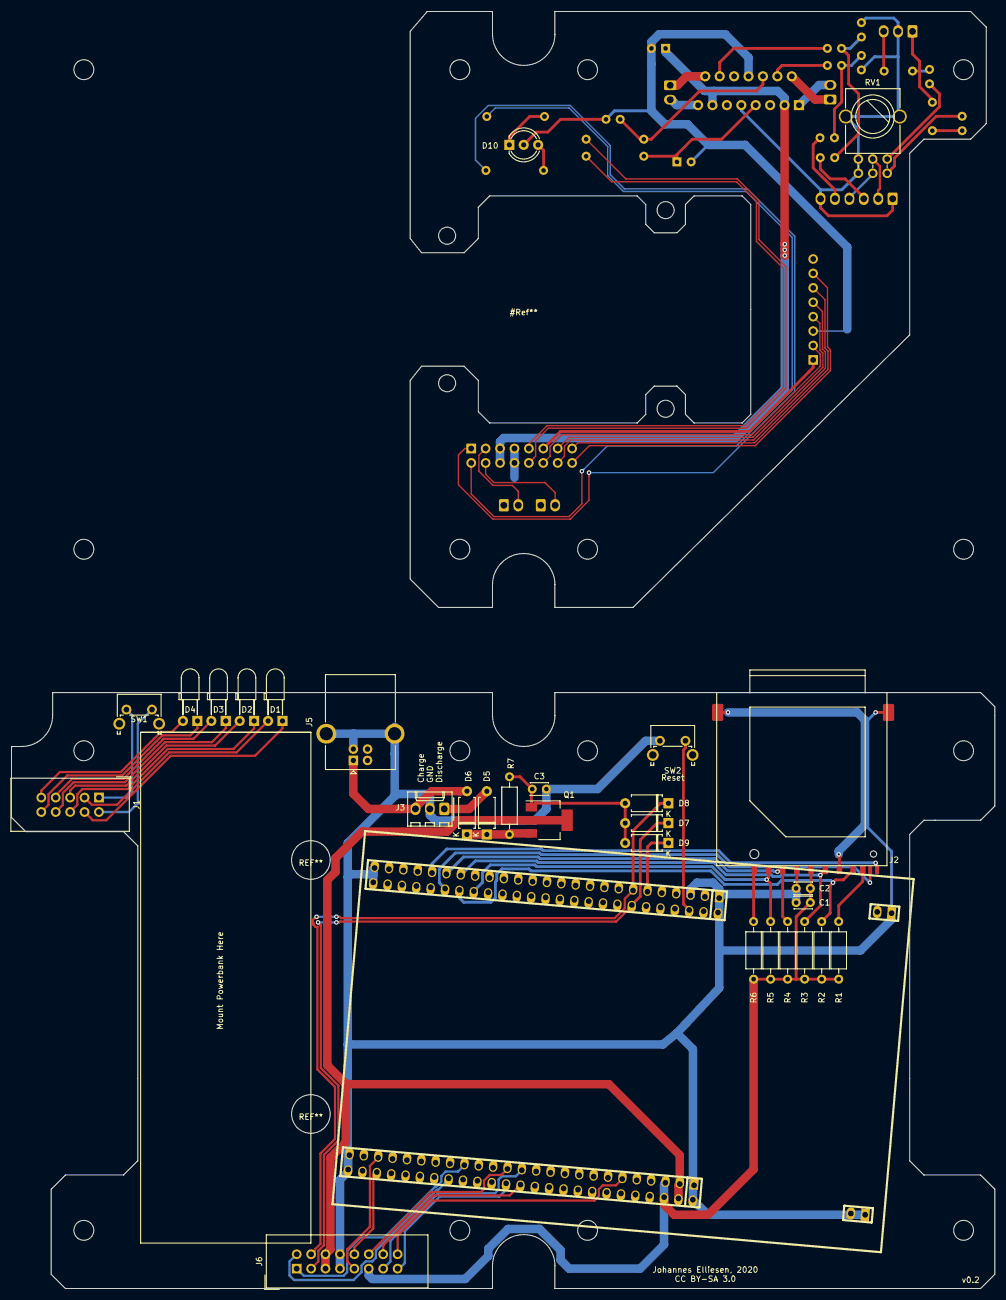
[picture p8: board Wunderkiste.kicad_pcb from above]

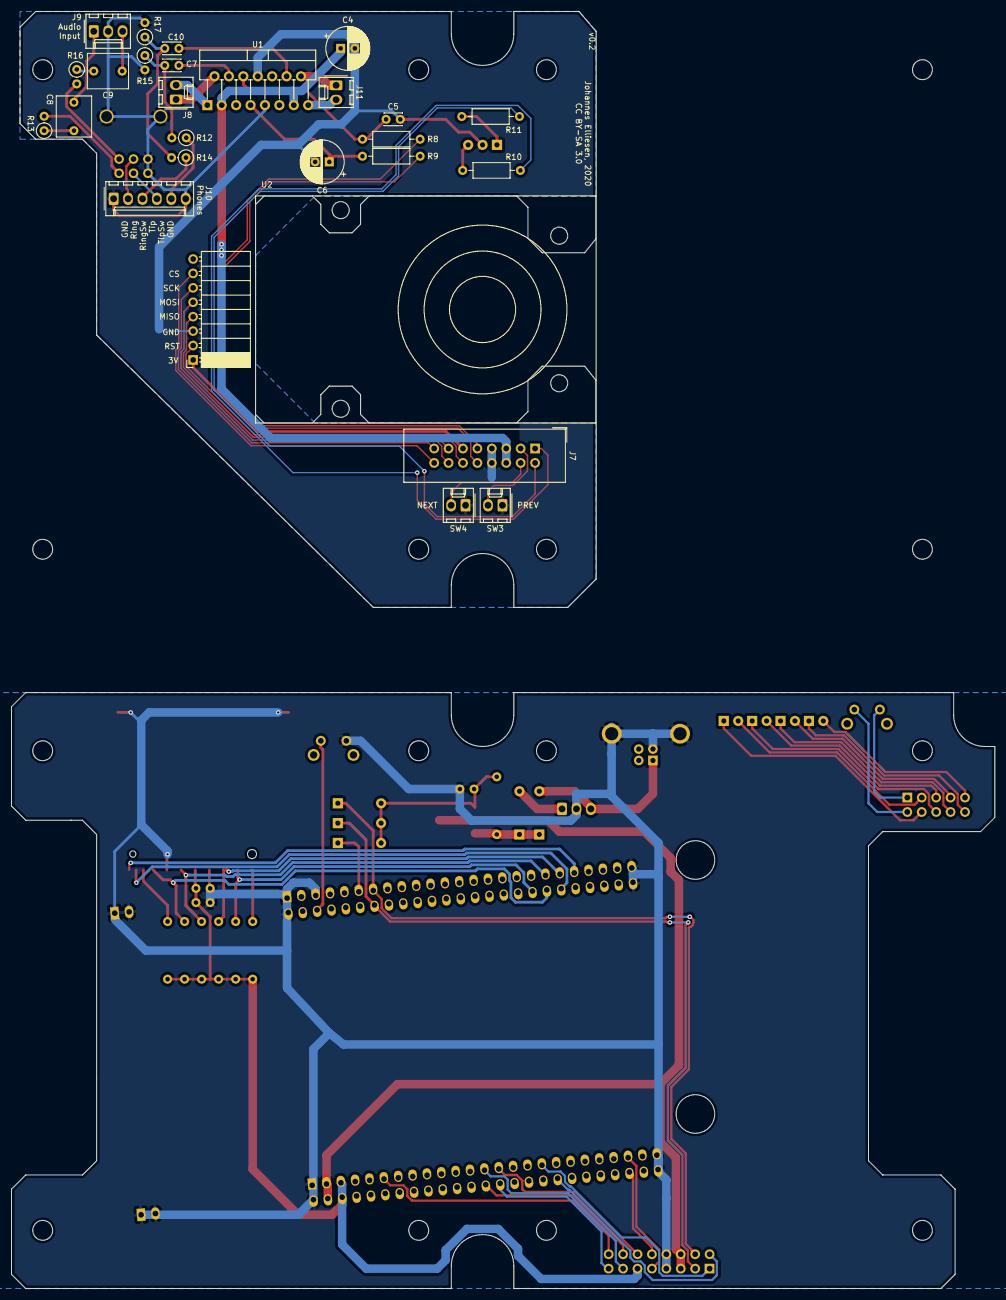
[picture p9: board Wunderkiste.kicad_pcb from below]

Board: 2 copper layers, 173.2 x 225.0 mm, 56 parts (26 on the bottom side), 71 nets.

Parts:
C1, C5: 1u; C_Disc_D3.0mm_W2.0mm_P2.50mm
C2, C3: 100n; C_Disc_D3.0mm_W2.0mm_P2.50mm
C4: 47u; CP_Radial_D7.5mm_P2.50mm
C6: 10u; CP_Radial_D7.5mm_P2.50mm
C7, C10: 220n; C_Disc_D3.0mm_W2.0mm_P2.50mm
C8, C9: 10u; C_Rect_L7.0mm_W6.0mm_P5.00mm
D1, D2, D3, D4: LED; LED_D3.0mm_Horizontal_O3.81mm_Z2.0mm
D5, D6, D7, D8, D9: 1N5819; D_A-405_P7.62mm_Horizontal
D10: LED_Dual_ACA; LED_D5.0mm-3
J1: Conn_01x10; IDC-Header_2x05_P2.54mm_Vertical
J2: SD_Card_Det; SD_Socket_SD-RSMT-2-10
J3: Powerbank; Molex_KK-254_AE-6410-03A_1x03_P2.54mm_Vertical
J4: STM32F4_Discovery; stm32f4_discovery
J5: USB_B; USB_B_OST_USB-B1HSxx_Horizontal
J6, J7: Conn_01x16; IDC-Header_2x08_P2.54mm_Vertical
J8: Spkr_L; Molex_KK-254_AE-6410-02A_1x02_P2.54mm_Vertical
J9: AudioIn; Molex_KK-254_AE-6410-03A_1x03_P2.54mm_Vertical
J10: Headphones; Molex_KK-254_AE-6410-06A_1x06_P2.54mm_Vertical
J11: Spkr_R; Molex_KK-254_AE-6410-02A_1x02_P2.54mm_Vertical
Q1: ISP75DP06LM; SOT-223
R1, R2, R3, R4, R5, R6, R7: 47k; R_Axial_DIN0207_L6.3mm_D2.5mm_P10.16mm_Horizontal
R8, R9: 10k; R_Axial_DIN0207_L6.3mm_D2.5mm_P10.16mm_Horizontal
R10: 470R; R_Axial_DIN0207_L6.3mm_D2.5mm_P10.16mm_Horizontal
R11: 2k2; R_Axial_DIN0207_L6.3mm_D2.5mm_P10.16mm_Horizontal
R12, R14, R15, R17: 10k; R_Axial_DIN0207_L6.3mm_D2.5mm_P2.54mm_Vertical
R13, R16: 0R; R_Axial_DIN0207_L6.3mm_D2.5mm_P2.54mm_Vertical
RV1: 50kA; 9mm_pot_dual
SW1: BatteryIndicator; SW_Tactile_SPST_Angled_PTS645Vx83-2LFS
SW2: Reset; SW_Tactile_SPST_Angled_PTS645Vx83-2LFS
SW3: PrevTrack; Molex_KK-254_AE-6410-02A_1x02_P2.54mm_Vertical
SW4: NextTrack; Molex_KK-254_AE-6410-02A_1x02_P2.54mm_Vertical
U1: TDA7266; TO-220-15_P2.54x2.54mm_StaggerOdd_Lead4.58mm_Vertical
U2: RFID_RC522_Board; RFID_RC_522_Board

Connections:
+3V0: C1.1, C2.1, J2.4, J4.95, J4.96, J6.11, J7.11, R1.1, R2.1, R3.1, R4.1, R5.1, R6.1, U2.1
+5V: C4.1, J4.97, J4.98, J6.5, J6.6, J7.5, J7.6, Q1.2, Q1.4, U1.3, U1.13
/AMP_MUTE: J4.56, J6.10
/AMP_MUTE_T: J7.10, R8.1
/AMP_STBY: J4.55, J6.9
/AMP_STBY_T: J7.9, R9.1
/POWER_HOLD: D9.1, J4.11
/RFID_CS: J4.89, J6.16
/RFID_CS_T: J7.16, U2.7
/RFID_MISO: J4.75, J6.13
/RFID_MISO_T: J7.13, U2.4
/RFID_MOSI: J4.76, J6.14
/RFID_MOSI_T: J7.14, U2.5
/RFID_RST: J4.73, J6.12
/RFID_RST_T: J7.12, U2.2
/RFID_SCK: J4.74, J6.15
/RFID_SCK_T: J7.15, U2.6
/Ring: J10.2, RV1.2
/RingNorm: J10.3, R14.1
/SD_AVAIL: J2.10, J4.40
/SD_CS: J2.1, J4.36, R5.2
/SD_MISO: J2.7, J4.38, R2.2
/SD_MOSI: J2.2, J4.39, R4.2
/SD_SCLK: J2.5, J4.37, R3.2
/SD_WRTPRT: J2.11, J4.41
/SW_NEXT: D8.1, J4.13, J6.4
/SW_NEXT_T: J7.4, SW4.2
/SW_PREV: D7.1, J4.14, J6.3
/SW_PREV_T: J7.3, SW3.2
/SW_RESET: J4.6, SW2.2
/TOP_LED_G: J4.67, J6.1
/TOP_LED_G_T: J7.1, R10.2
/TOP_LED_R: J4.66, J6.2
/TOP_LED_R_T: J7.2, R11.1
/Tip: J10.4, RV1.5
/TipNorm: J10.5, R12.1
GND: C1.2, C2.2, C3.2, C4.2, C5.2, C6.2, D10.2, J2.3, J2.6, J2.12, J3.2, J4.1, J4.2, J4.5, J4.49, J4.50, J4.51, J4.52, J4.99, J4.100, J5.4, J5.5, J6.7, J6.8, J7.7, J7.8, J9.2, J10.1, J10.6, R15.2, R17.2, RV1.1, RV1.4, RV1.7, SW2.1, SW3.1, SW4.1, U1.8, U1.9, U2.3
unnamed: C3.1, D7.2, D8.2, D9.2, Q1.1, R7.2
unnamed: C5.1, R8.2, U1.6
unnamed: C6.1, R9.2, U1.7
unnamed: C7.1, U1.4
unnamed: C7.2, R12.2, R15.1
unnamed: C8.1, R13.1
unnamed: C8.2, J9.1
unnamed: C9.1, J9.3
unnamed: C9.2, R16.1
unnamed: C10.1, U1.12
unnamed: C10.2, R14.2, R17.1
unnamed: D1.1, J1.4
unnamed: D1.2, J1.3
unnamed: D2.1, J1.6
unnamed: D2.2, J1.5
unnamed: D3.1, J1.8
unnamed: D3.2, J1.7
unnamed: D4.1, J1.10
unnamed: D4.2, J1.9
unnamed: D5.1, D6.1, Q1.3, R7.1
unnamed: D5.2, J3.1
unnamed: D6.2, J3.3, J5.1
unnamed: D10.1, R11.2
unnamed: D10.3, R10.1
unnamed: J1.1, SW1.1
unnamed: J1.2, SW1.2
unnamed: J2.8, R1.2
unnamed: J2.9, R6.2
unnamed: J8.1, U1.2
unnamed: J8.2, U1.1
unnamed: J11.1, U1.14
unnamed: J11.2, U1.15
unnamed: R13.2, RV1.6
unnamed: R16.2, RV1.3

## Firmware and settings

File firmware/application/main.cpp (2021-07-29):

/**	
 * Copyright (C) Johannes Elliesen, 2021
 * 
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
 * You should have received a copy of the GNU General Public License
 * along with this program.  If not, see <http://www.gnu.org/licenses/>.
 */

extern "C"
{
#include "stm32f4xx.h"
#include "core_cm4.h"
#include "stm32f4xx_conf.h"
}
#include "Platform.h"
#include "Library.h"
#include "File.h"
#include "Wunderkiste.h"
#include "RFID.h"
#include "UI.h"
#include "UiEventQueue.h"
#include <type_traits>
#include <memory>

using AudioStreamPlayerType = AudioStreamPlayer<WunderkisteAudioOutput>;
using Mp3DirectoryPlayerType = Mp3DirectoryPlayer<AudioStreamPlayerType>;

LateInitializedObject<AudioStreamPlayerType> streamPlayer;
LateInitializedObject<Mp3DirectoryPlayerType> mp3DirectoryPlayer;
LateInitializedObject<UiEventQueue> uiEventQueue;
LateInitializedObject<Wunderkiste> wunderkisteApp;

/**
 * Main function. Called when startup code is done with
 * copying memory and setting up clocks.
 */
int main(void)
{
    // initialize the platform
    Power::initAndLatchOn();
    WatchdogTimer::init();
    Systick::init();
    LED::init();
    const bool filesystemMounted = Filesystem::mount();
    if (!filesystemMounted)
    {
        // display error code
        LED::setLed(LED::Pattern::errNoCard);
        // wait a while and auto-shutdown
        Power::enableOrResetAutoShutdownTimer();
        while (1)
        {
            WatchdogTimer::reset();
        }
    }

    uiEventQueue.create();

    RfidReader::init();
    ButtonScanner::init(*uiEventQueue); // debouncing executed via the systick interrupt

    streamPlayer.create();
    mp3DirectoryPlayer.create(*streamPlayer);
    wunderkisteApp.create(*uiEventQueue, *mp3DirectoryPlayer);

    while (1)
    {
        WatchdogTimer::reset();
        RfidReader::readAndGenerateEvents(*uiEventQueue);
        wunderkisteApp->handleEvents();
        streamPlayer->refillBuffers();
    }
}

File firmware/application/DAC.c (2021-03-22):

/**	
 * Copyright (C) Johannes Elliesen, 2021
 * 
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
 * You should have received a copy of the GNU General Public License
 * along with this program.  If not, see <http://www.gnu.org/licenses/>.
 */

#include "stm32f4xx_conf.h"
#include "stm32f4xx_rcc.h"
#include "stm32f4xx_gpio.h"
#include "stm32f4xx_dma.h"
#include "stm32f4xx.h"

#include <stdlib.h>
#include <stdbool.h>

static void WriteRegister(uint8_t address, uint8_t value);
static void StartAudioDMAAndRequestBuffers();
static void StopAudioDMA();
void SetAudioVolume(int volume);
bool ProvideAudioBufferWithoutBlocking(void* samples, int numsamples);
typedef void AudioCallbackFunction(void* context, int buffer);

static AudioCallbackFunction* CallbackFunction;
static void* CallbackContext;
static int16_t* volatile NextBufferSamples;
static volatile int NextBufferLength;
static volatile int BufferNumber;
static volatile bool DMARunning;

void InitializeAudio(int plln, int pllr, int i2sdiv, int i2sodd)
{
    GPIO_InitTypeDef GPIO_InitStructure;

    // Intitialize state.
    CallbackFunction = NULL;
    CallbackContext = NULL;
    NextBufferSamples = NULL;
    NextBufferLength = 0;
    BufferNumber = 0;
    DMARunning = false;

    // Turn on peripherals.
    RCC_AHB1PeriphClockCmd(RCC_AHB1Periph_GPIOA, ENABLE);
    RCC_AHB1PeriphClockCmd(RCC_AHB1Periph_GPIOB, ENABLE);
    RCC_AHB1PeriphClockCmd(RCC_AHB1Periph_GPIOC, ENABLE);
    RCC_AHB1PeriphClockCmd(RCC_AHB1Periph_GPIOD, ENABLE);
    RCC_AHB1PeriphClockCmd(RCC_AHB1Periph_DMA1, ENABLE);

    RCC_APB1PeriphClockCmd(RCC_APB1Periph_I2C1, ENABLE);
    RCC_APB1PeriphClockCmd(RCC_APB1Periph_SPI3, ENABLE);

    // Configure reset pin.
    GPIO_InitStructure.GPIO_Pin = GPIO_Pin_4;
    GPIO_InitStructure.GPIO_Mode = GPIO_Mode_OUT;
    GPIO_InitStructure.GPIO_OType = GPIO_OType_PP;
    GPIO_InitStructure.GPIO_Speed = GPIO_Speed_50MHz;
    GPIO_InitStructure.GPIO_PuPd = GPIO_PuPd_NOPULL;
    GPIO_Init(GPIOD, &GPIO_InitStructure);

    // Configure I2C SCL and SDA pins.
    GPIO_InitStructure.GPIO_Pin = GPIO_Pin_6 | GPIO_Pin_9;
    GPIO_InitStructure.GPIO_Speed = GPIO_Speed_50MHz;
    GPIO_InitStructure.GPIO_Mode = GPIO_Mode_AF;
    GPIO_InitStructure.GPIO_OType = GPIO_OType_OD;
    GPIO_InitStructure.GPIO_PuPd = GPIO_PuPd_NOPULL;
    GPIO_Init(GPIOB, &GPIO_InitStructure);

    GPIO_PinAFConfig(GPIOB, GPIO_PinSource6, GPIO_AF_I2C1);
    GPIO_PinAFConfig(GPIOB, GPIO_PinSource9, GPIO_AF_I2C1);

    // Configure I2S MCK, SCK, SD pins.
    GPIO_InitStructure.GPIO_Pin = GPIO_Pin_7 | GPIO_Pin_10 | GPIO_Pin_12;
    GPIO_InitStructure.GPIO_Speed = GPIO_Speed_50MHz;
    GPIO_InitStructure.GPIO_Mode = GPIO_Mode_AF;
    GPIO_InitStructure.GPIO_OType = GPIO_OType_PP;
    GPIO_InitStructure.GPIO_PuPd = GPIO_PuPd_NOPULL;
    GPIO_Init(GPIOC, &GPIO_InitStructure);

    GPIO_PinAFConfig(GPIOC, GPIO_PinSource7, GPIO_AF_SPI3);
    GPIO_PinAFConfig(GPIOC, GPIO_PinSource10, GPIO_AF_SPI3);
    GPIO_PinAFConfig(GPIOC, GPIO_PinSource12, GPIO_AF_SPI3);

    // Configure I2S WS pin.
    GPIO_InitStructure.GPIO_Pin = GPIO_Pin_4;
    GPIO_InitStructure.GPIO_Speed = GPIO_Speed_50MHz;
    GPIO_InitStructure.GPIO_Mode = GPIO_Mode_AF;
    GPIO_InitStructure.GPIO_OType = GPIO_OType_PP;
    GPIO_InitStructure.GPIO_PuPd = GPIO_PuPd_NOPULL;
    GPIO_Init(GPIOA, &GPIO_InitStructure);

    GPIO_PinAFConfig(GPIOA, GPIO_PinSource4, GPIO_AF_SPI3);

    // Reset the codec.
    GPIOD->BSRRH = 1 << 4;
    for (volatile int i = 0; i < 0x4fff; i++)
    {
        __asm__ volatile("nop");
    }
    GPIOD->BSRRL = 1 << 4;

    // Reset I2C.
    RCC_APB1PeriphResetCmd(RCC_APB1Periph_I2C1, ENABLE);
    RCC_APB1PeriphResetCmd(RCC_APB1Periph_I2C1, DISABLE);

    // Configure I2C.
    uint32_t pclk1 = 42000000;

    I2C1->CR2 = pclk1 / 1000000; // Configure frequency and disable interrupts and DMA.
    I2C1->OAR1 = I2C_OAR1_ADDMODE | 0x33;

    // Configure I2C speed in standard mode.
    const uint32_t i2c_speed = 100000;
    int ccrspeed = pclk1 / (i2c_speed * 2);
    if (ccrspeed < 4)
    {
        ccrspeed = 4;
    }
    I2C1->CCR = ccrspeed;
    I2C1->TRISE = pclk1 / 1000000 + 1;

    I2C1->CR1 = I2C_CR1_ACK | I2C_CR1_PE; // Enable and configure the I2C peripheral.

    // Configure codec.
    WriteRegister(0x02, 0x01); // Keep codec powered off.
    WriteRegister(0x04, 0xaf); // SPK always off and HP always on.

    WriteRegister(0x05, 0x81); // Clock configuration: Auto detection.
    WriteRegister(0x06, 0x04); // Set slave mode and Philips audio standard.

    SetAudioVolume(0xff);

    // Power on the codec.
    WriteRegister(0x02, 0x9e);

    // Configure codec for fast shutdown.
    WriteRegister(0x0a, 0x00); // Disable the analog soft ramp.
    WriteRegister(0x0e, 0x04); // Disable the digital soft ramp.

    WriteRegister(0x27, 0x00); // Disable the limiter attack level.
    WriteRegister(0x1f, 0x0f); // Adjust bass and treble levels.

    WriteRegister(0x1a, 0b0011000); // Adjust PCM volume level.
    WriteRegister(0x1b, 0b0011000);

    // Disable I2S.
    SPI3->I2SCFGR = 0;

    // I2S clock configuration
    RCC->CFGR &= ~RCC_CFGR_I2SSRC; // PLLI2S clock used as I2S clock source.
    RCC->PLLI2SCFGR = (pllr << 28) | (plln << 6);

    // Enable PLLI2S and wait until it is ready.
    RCC->CR |= RCC_CR_PLLI2SON;
    while (!(RCC->CR & RCC_CR_PLLI2SRDY))
        ;

    // Configure I2S.
    SPI3->I2SPR = i2sdiv | (i2sodd << 8) | SPI_I2SPR_MCKOE;
    SPI3->I2SCFGR = SPI_I2SCFGR_I2SMOD | SPI_I2SCFGR_I2SCFG_1
                    | SPI_I2SCFGR_I2SE; // Master transmitter, Phillips mode, 16 bit values, clock polarity low, enable.
}

void AudioOn()
{
    WriteRegister(0x02, 0x9e);
    SPI3->I2SCFGR = SPI_I2SCFGR_I2SMOD | SPI_I2SCFGR_I2SCFG_1
                    | SPI_I2SCFGR_I2SE; // Master transmitter, Phillips mode, 16 bit values, clock polarity low, enable.
}

void AudioOff()
{
    WriteRegister(0x02, 0x01);
    SPI3->I2SCFGR = 0;
}

void SetAudioVolume(int volume)
{
    WriteRegister(0x20, (volume + 0x19) & 0xff);
    WriteRegister(0x21, (volume + 0x19) & 0xff);
}

void OutputAudioSample(int16_t sample)
{
    while (!(SPI3->SR & SPI_SR_TXE))
        ;
    SPI3->DR = sample;
}

void OutputAudioSampleWithoutBlocking(int16_t sample)
{
    SPI3->DR = sample;
}

void PlayAudioWithCallback(AudioCallbackFunction* callback, void* context)
{
    StopAudioDMA();

    NVIC_EnableIRQ(DMA1_Stream7_IRQn);
    NVIC_SetPriority(DMA1_Stream7_IRQn, 4);

    SPI3->CR2 |= SPI_CR2_TXDMAEN; // Enable I2S TX DMA request.

    CallbackFunction = callback;
    CallbackContext = context;
    BufferNumber = 0;

    if (CallbackFunction)
        CallbackFunction(CallbackContext, BufferNumber);
}

void StopAudio()
{
    StopAudioDMA();
    SPI3->CR2 &= ~SPI_CR2_TXDMAEN; // Disable I2S TX DMA request.
    NVIC_DisableIRQ(DMA1_Stream7_IRQn);
    CallbackFunction = NULL;
}

void ProvideAudioBuffer(void* samples, int numsamples)
{
    while (!ProvideAudioBufferWithoutBlocking(samples, numsamples))
        __asm__ volatile("wfi");
}
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

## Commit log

2020-12-29 Added initial firmware source files
    [erase_f0xx.cfg, erase_f10x.cfg, erase_f37x.cfg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]
2020-12-29 Added hardware designs v0.1
    [Wunderkiste.kicad_pcb, Wunderkiste.sch]
2020-12-29 Added button debouncing; added UI event queue; improved previous button behaviour
    Fixes #5
2020-12-29 removed duplicate STM32 peripheral library
2020-12-30 Included the current contents of the wiki; Added action that copies "docs/wiki" to the GitHub wiki on each push on "master"
2021-01-02 Reallocated custom kicad symbols into a local symbol library
    [Wunderkiste.kicad_pcb, Wunderkiste.sch]
2021-01-02 Fixed DRC errors in the pcb file
    [Wunderkiste.kicad_pcb]
2021-01-02 Fixed ERC errors
    [Wunderkiste.sch]
2021-01-02 KiBot now generates the drill template from the Dwgs.User layer
2021-01-02 Improved drill template on the Dwgs.User layer
    [Wunderkiste.kicad_pcb]
2021-01-09 Fixed Mosfet that had the wrong part number
    [Wunderkiste.sch]
2021-01-10 Added BOM
    [BOM.xlsx]
2021-02-08 Switched firmware to C++17
2021-03-21 Fixed LED driver having an accidental Pullup enabled
    [UI.cpp]
2021-03-22 Improved reliability of SD card driver
2021-03-22 Improved firmware update instructions for older STM32F4 Discovery boards
2021-03-22 Removed unused STM source files for STM32F0xx, STM32F10x, STM32F37x and DSP_Lib
2021-03-22 Added missing GPL header
    [AudioOutput.cpp, DAC.c, DAC.h]
2021-04-09 BOM.xlsx is now added to the release artifacts
2021-04-09 Small fixes in BOM.xlsx
    [BOM.xlsx]
2021-07-25 fix: correctly display error code when SD cannot be mounted
    [main.cpp]
2021-07-29 fix: improve mounting/unmounting of SD card
    [Platform.cpp]

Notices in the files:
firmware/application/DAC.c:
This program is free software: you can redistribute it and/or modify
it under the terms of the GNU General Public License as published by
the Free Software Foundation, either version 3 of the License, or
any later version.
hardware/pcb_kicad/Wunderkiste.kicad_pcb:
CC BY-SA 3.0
